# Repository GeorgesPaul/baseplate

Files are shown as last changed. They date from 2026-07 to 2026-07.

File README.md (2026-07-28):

# Baseplate

| | |
|---|---|
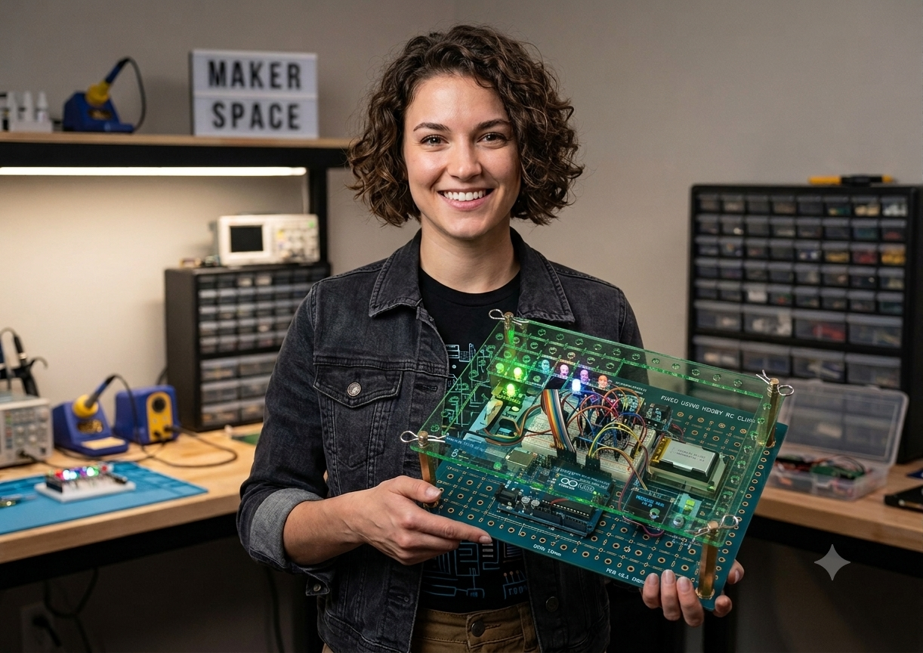
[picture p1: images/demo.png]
A finished stack with electronics mounted
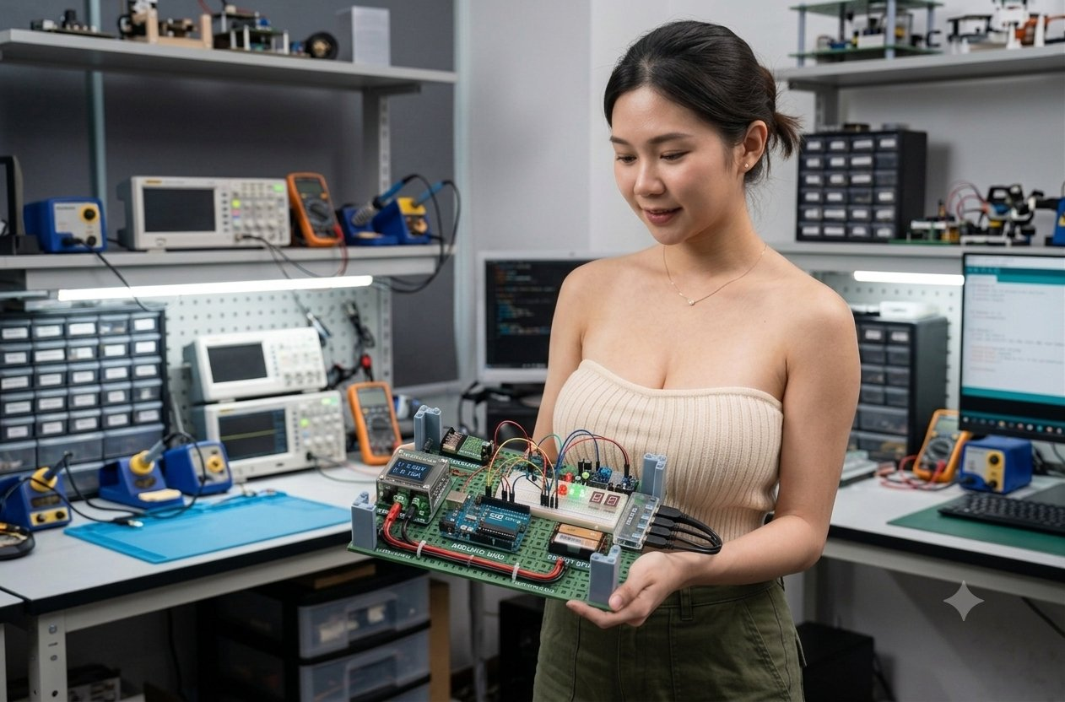
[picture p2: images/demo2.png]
A single plate carrying an Arduino, a breadboard and sensor modules
|  |  |

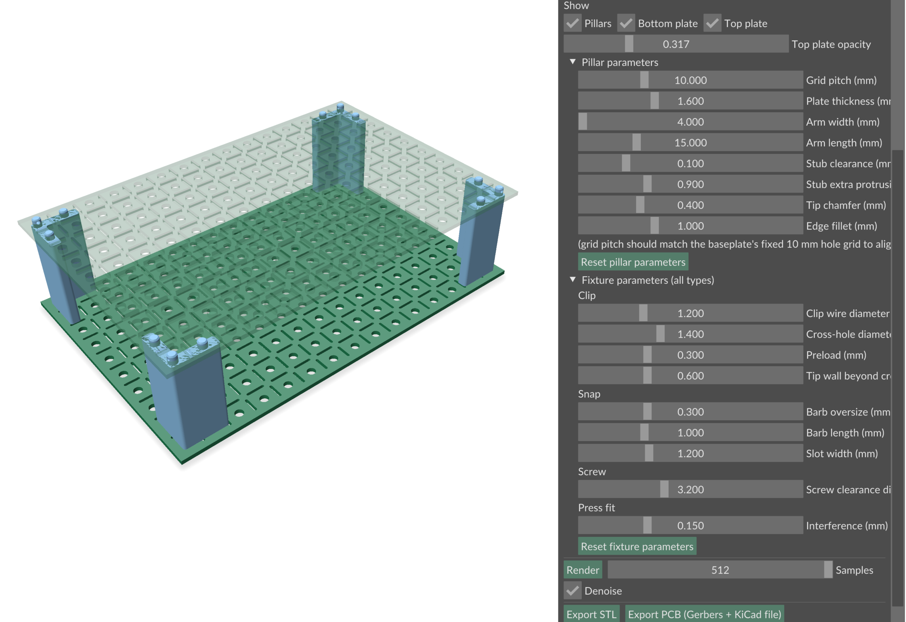
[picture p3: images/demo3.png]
The live parameter viewer: a 150x100 stack with the top plate at 32% opacity, next to the panel of sliders that drives it


A parametric prototyping stack: a snappable M3 grid plate fabricated as a PCB, plus 3D-printed
L-shaped corner pillars that hold two plates apart.

The plate is an ordinary 1.6 mm PCB with no copper: M3 clearance holes on a 10 mm grid, and milled
snap lines along every grid line so you can break any rectangular sub-plate out of a larger sheet by
hand. The pillars clip into those same holes, so a bottom plate, four pillars and a top plate make a
rigid enclosure-less chassis for a board, a battery, a sensor stack, or whatever else.

Everything is generated from code. The hole and slot pattern lives in one module
(`PCB/baseplate_geometry.py`) that feeds both the production KiCad board and the live 3D preview, so
the thing you look at is the thing that gets fabricated.

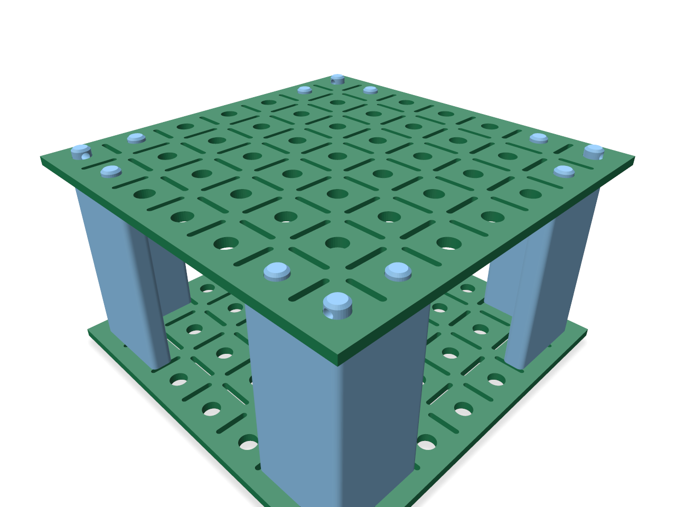
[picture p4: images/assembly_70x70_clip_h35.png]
70x70 assembly with clip pillars


## Configurations

Board size, pillar height and fixture type are all sliders in the viewer. A few points in that space:

### 40 x 40 mm, snap fixture, 20 mm pillars

The smallest useful stack. 16 M3 holes, 24 snap slots.

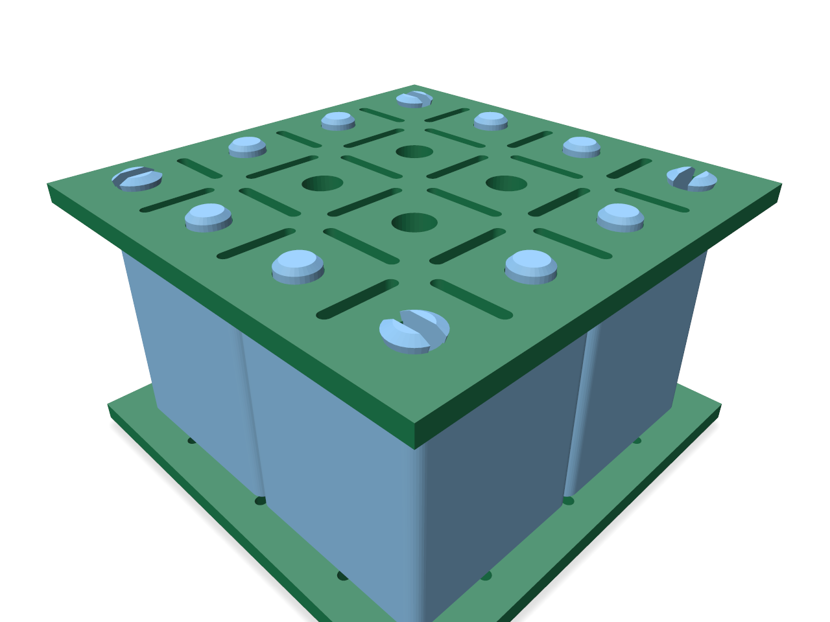
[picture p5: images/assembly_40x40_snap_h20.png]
40x40 snap assembly


### 70 x 70 mm, clip fixture, 35 mm pillars

The default. 49 M3 holes, 84 snap slots. Corner stubs are cross-drilled for an RC-style wire clip.

70x70 clip assembly

### 150 x 80 mm, screw fixture, 50 mm pillars

Boards do not have to be square. 120 M3 holes, 217 snap slots. Each pillar is bored through for a
single bolt that clamps both plates.

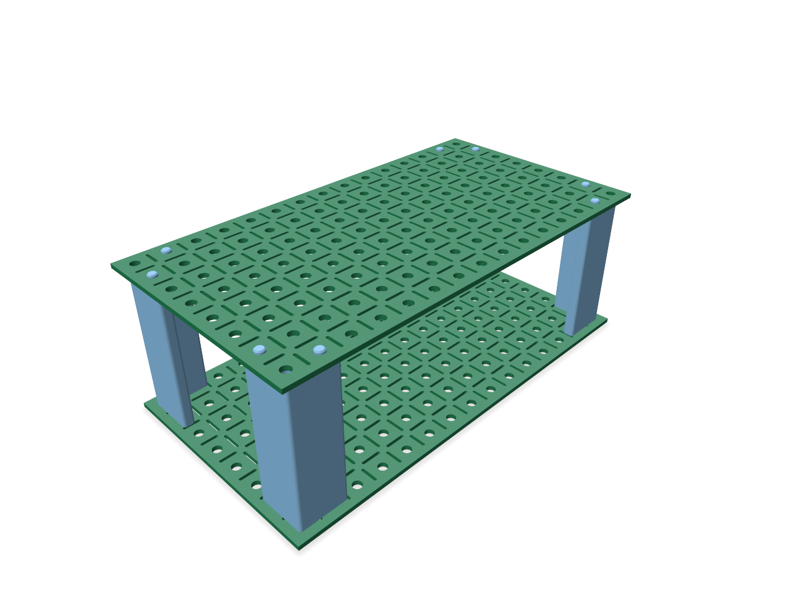
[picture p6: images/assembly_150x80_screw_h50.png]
150x80 screw assembly


### 250 x 250 mm, clip fixture, 50 mm pillars

The full panel, which is also the largest board most cheap fab houses take at the low price tier.
625 M3 holes, 1200 snap slots.

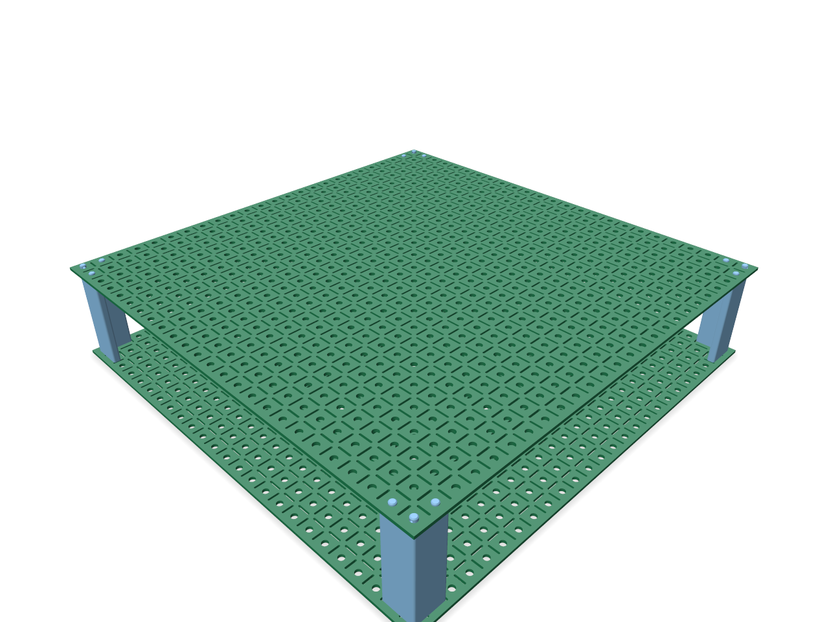
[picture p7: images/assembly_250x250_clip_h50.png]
250x250 clip assembly


### Top plate off

Pillars and each plate have their own show/hide checkbox, so you can drop the top plate and look at
what the corner stubs are actually doing. Here the clip fixture's cross-drilled holes are visible.

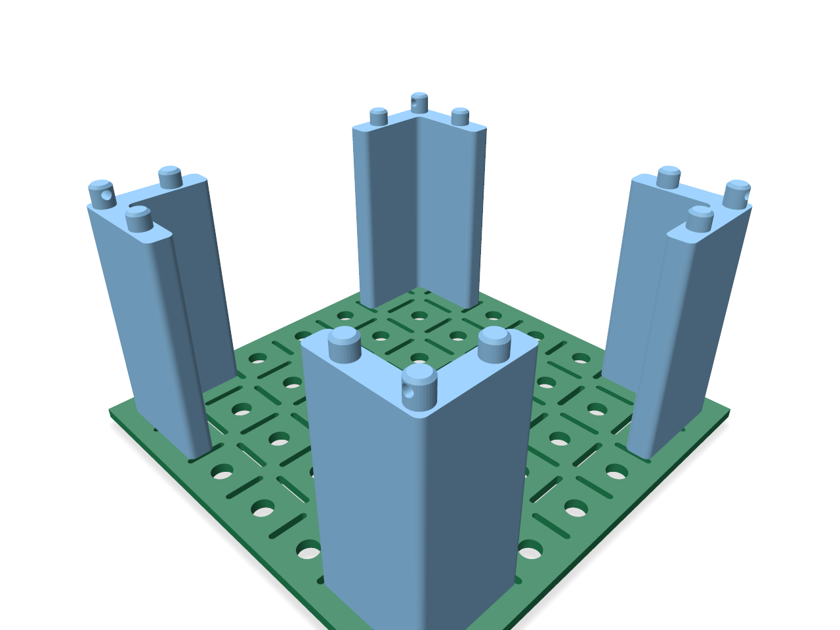
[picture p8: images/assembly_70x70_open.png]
70x70 assembly with the top plate hidden


### Top plate see-through

The top plate also has an opacity slider, for when you want the lid in place but still need to see
what is underneath it. Here it is at 40%.

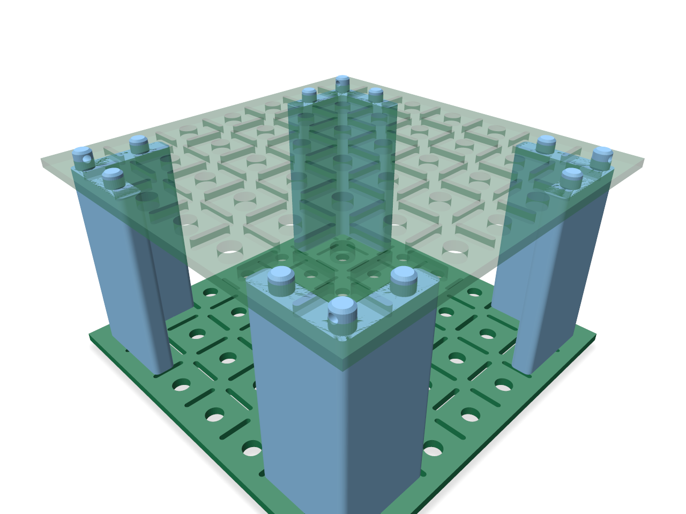
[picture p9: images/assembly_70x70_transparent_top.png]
70x70 assembly with a semi-transparent top plate


### Snap lines off

The break-off slots are a checkbox. Turn them off for a plain drilled grid plate: nothing to snap
along, nothing to crack in shipping, and the full stiffness of an uncut sheet.

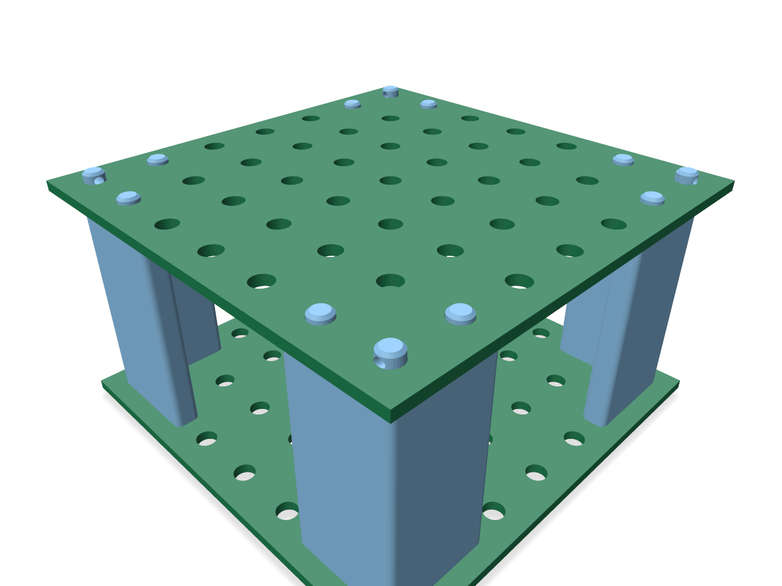
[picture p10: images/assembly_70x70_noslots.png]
70x70 assembly with no snap lines


## Fixture types

All four pillars share the same L-shaped body and the same three-stub footprint (corner stub plus one
stub a grid pitch away along each arm). Only the corner stub changes, which is what retains the plate.

| | |
|---|---|
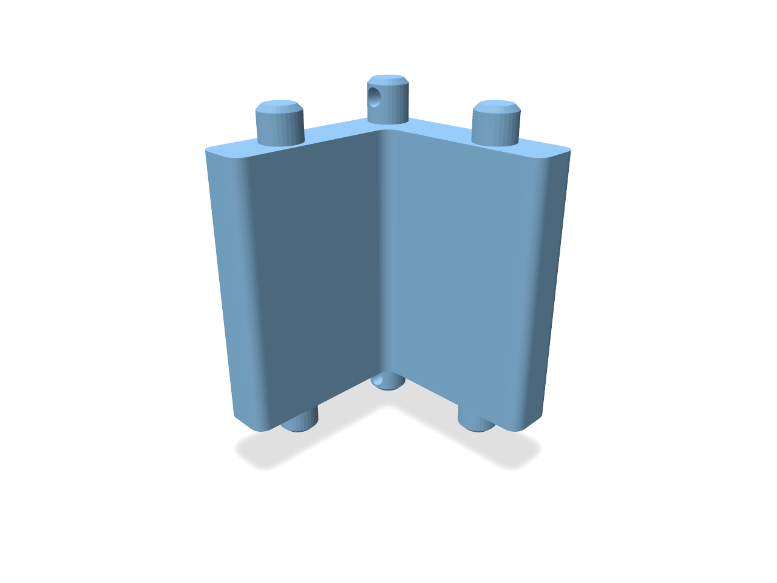
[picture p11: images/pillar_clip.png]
clip pillar
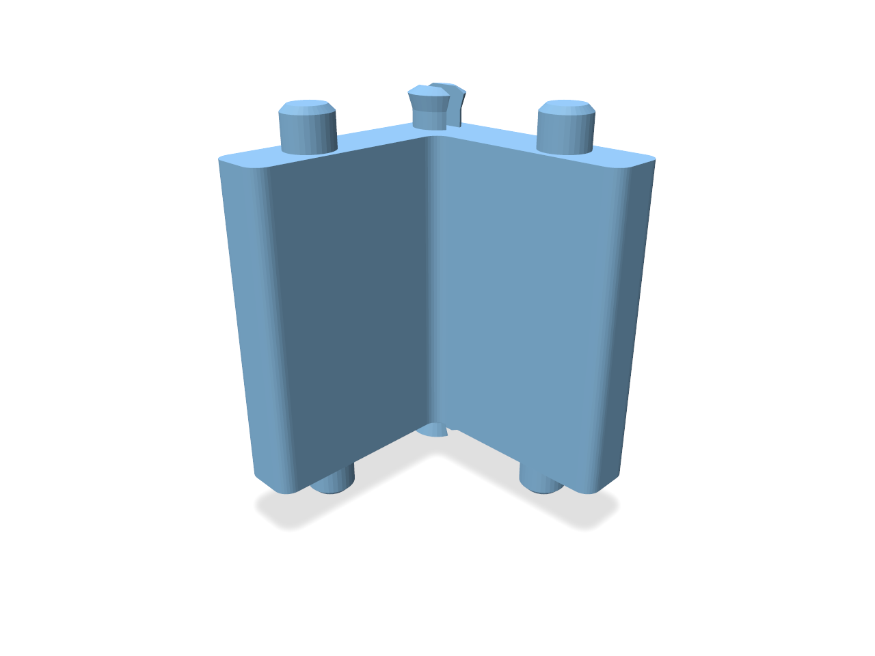
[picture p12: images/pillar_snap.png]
snap pillar
| **clip** <br> Cross-drilled stub for an RC-style wire clip. Preloaded so the installed clip clamps the plate down. <br>  | **snap** <br> Split cantilever boss with a barbed tip. No separate part to lose, and tolerant of stackup error. <br>  |
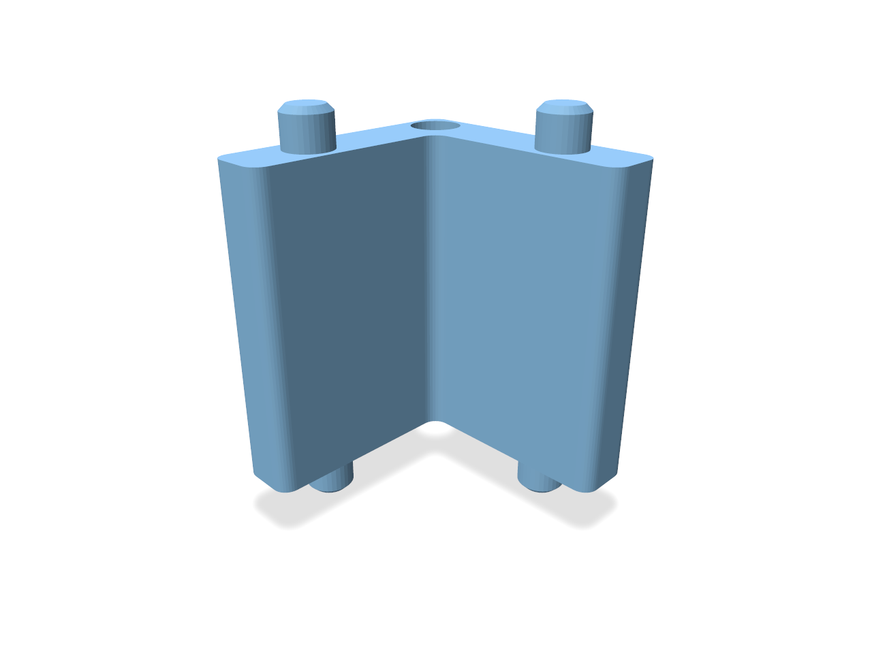
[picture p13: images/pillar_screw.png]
screw pillar
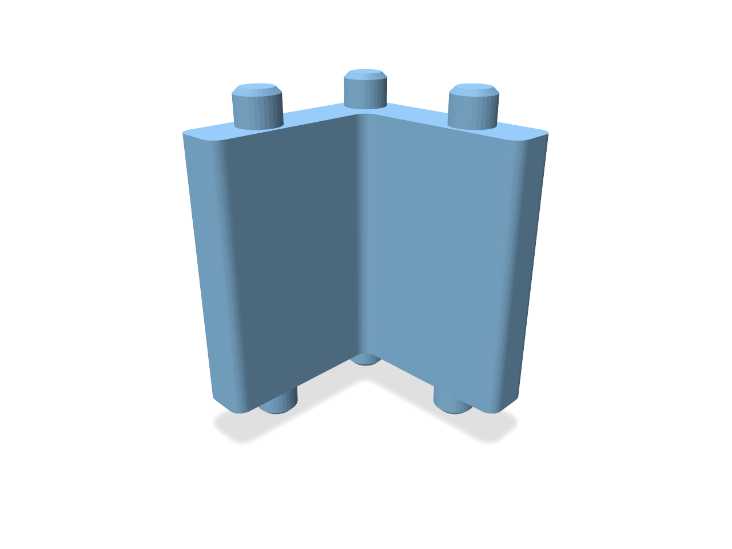
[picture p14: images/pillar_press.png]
press pillar
| **screw** <br> Plain slip-fit stubs plus a coaxial clearance bore through the whole body for one bolt. <br>  | **press** <br> Plain stubs sized for a light interference fit. Nothing else, for permanent stacks. <br>  |

Looking down at the corner stub, where the four types differ:

| clip | snap | screw | press |
|---|---|---|---|
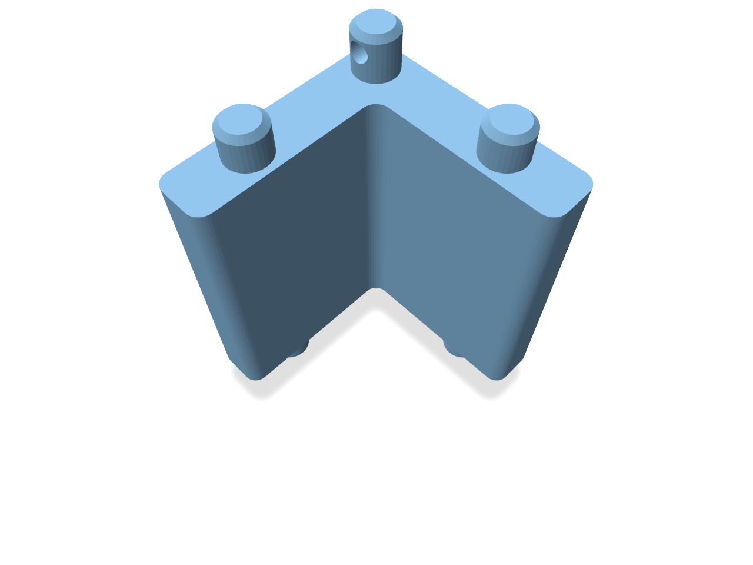
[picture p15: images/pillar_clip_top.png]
clip from above
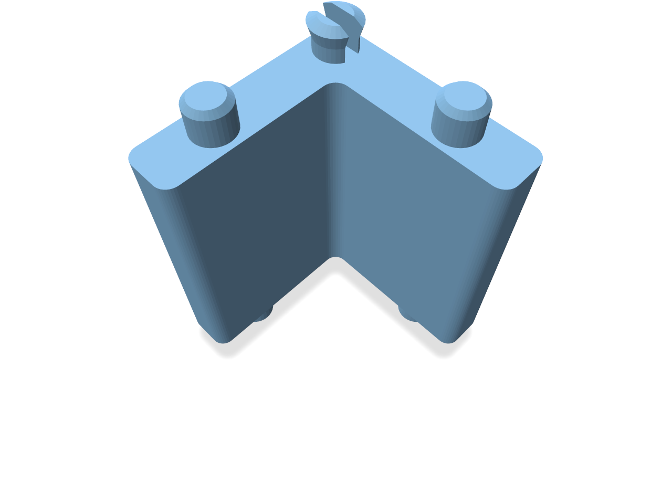
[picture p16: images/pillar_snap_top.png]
snap from above
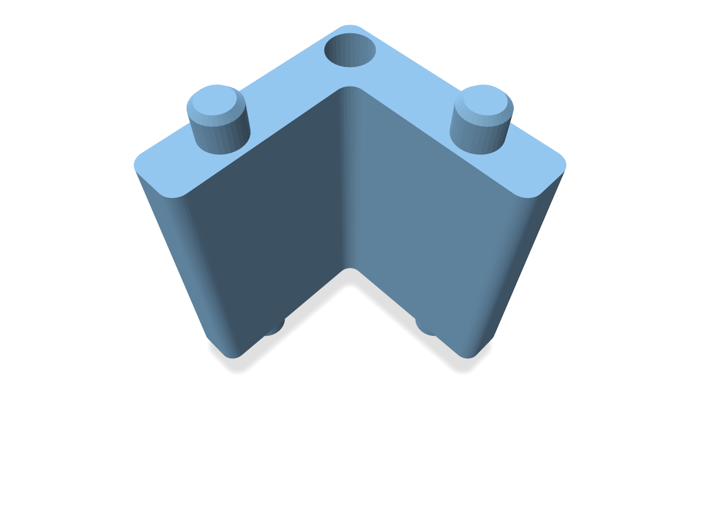
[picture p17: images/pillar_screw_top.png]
screw from above
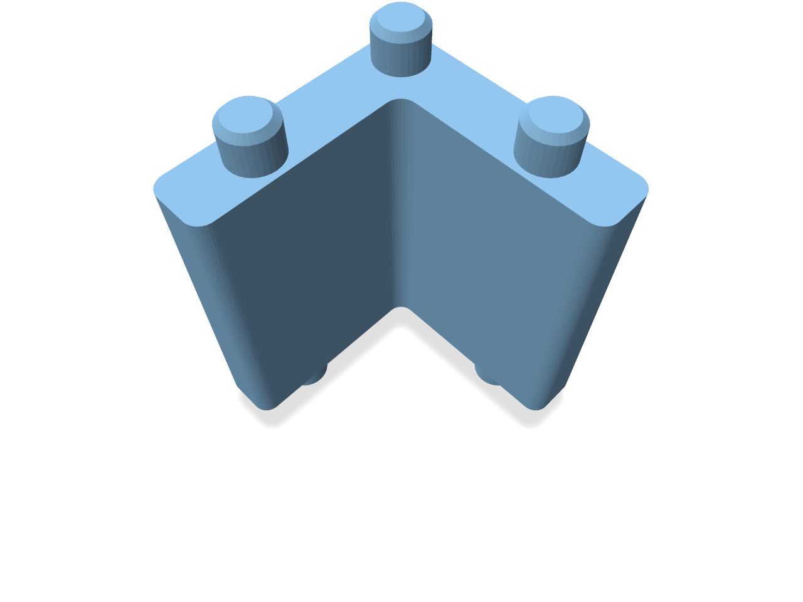
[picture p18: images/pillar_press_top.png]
press from above
|  |  |  |  |

## The board itself

Rendered from the generated KiCad file, 250 x 250 mm:

| Top | Perspective |
|---|---|
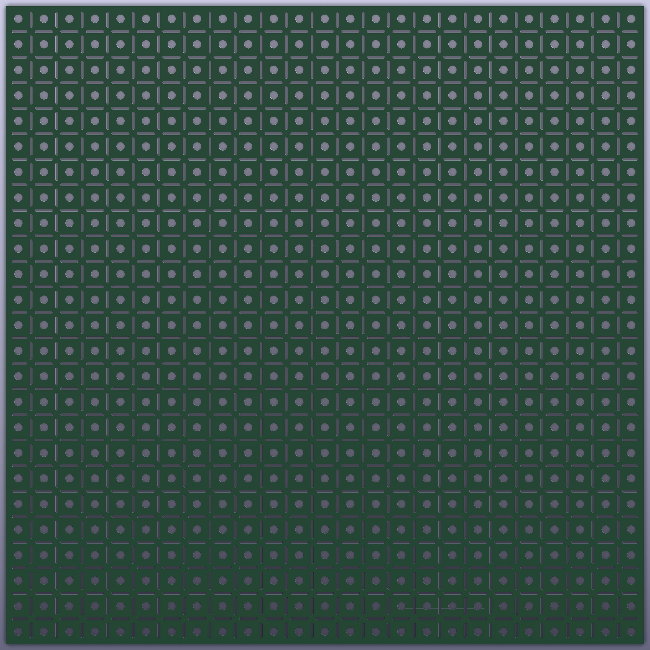
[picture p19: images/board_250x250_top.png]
board top render
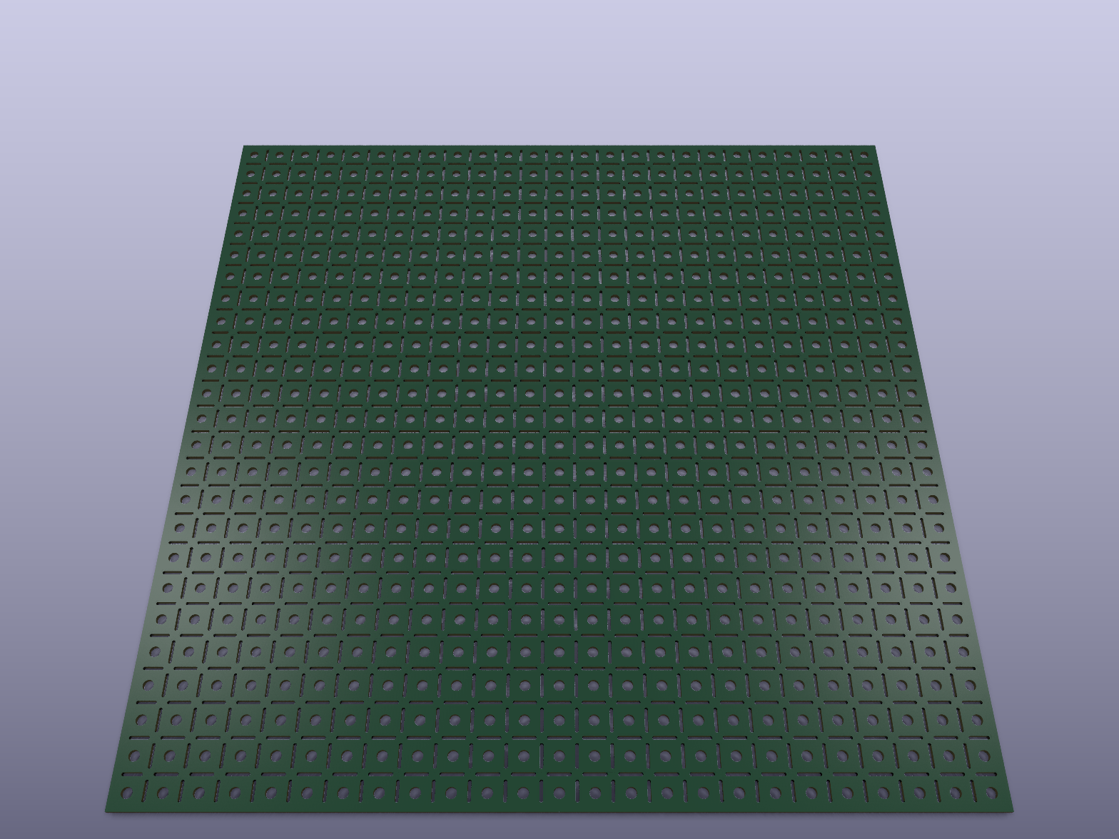
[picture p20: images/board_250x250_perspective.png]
board perspective render
|  |  |

Each 10 mm cell carries one M3 clearance hole in its center. Every interior grid line is a run of
1.0 mm milled NPTH slots, one per cell, each stopping short of the line crossings so a solid web
straddles every crossing. Those webs are the only thing holding the panel together along a break
line, and they are what you tune.

## Break-off strength

The 70 x 70 board close up, where the webs are legible:

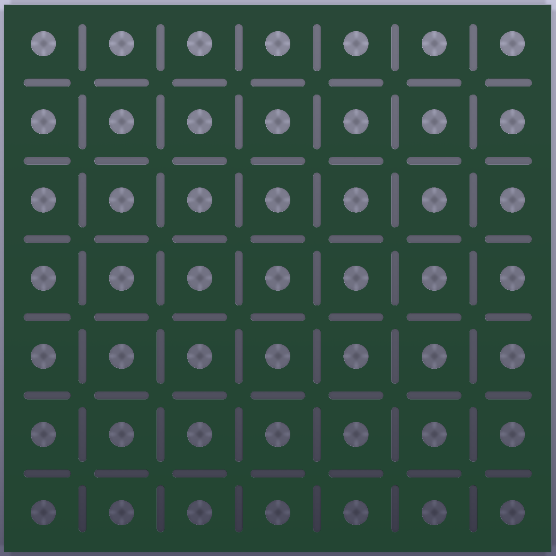
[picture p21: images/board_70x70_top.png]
70x70 board top render


Two numbers set how hard the panel is to snap:

- **`web`** (default 3.0 mm), the solid material left at each interior line crossing.
- **`edge_web`** (default 2.5 mm), the solid margin between the last slot and the board edge. This
  one matters more than its size suggests: the board edge is where a crack starts, so a thin edge web
  is what makes a panel come apart in the box.

Both are exposed as sliders in the viewer and as `--web` / `--edge-web` on the generator. The viewer
prints the resulting solid fraction of a break line as you drag them, and the generator prints it on
export:

```
snap slots: 84 (web 3 mm, edge web 2.5 mm)
  break line along X: 33% solid (23.0 mm of 70 mm)
  break line along Y: 33% solid (23.0 mm of 70 mm)
```

The first fabricated boards broke apart far too easily. That design used 2.5 mm webs and a 0.8 mm
edge web, and then perforated every web with a plus-pattern of 0.5 mm mouse bites. Three of those
bites landed directly on the break line, leaving about 1.0 mm of a 2.5 mm web as four 0.25 mm
ligaments, with the drilled holes acting as crack starters on top of that. A 70 mm break line held
roughly 7.6 mm of FR4.

The current design drops mouse bites entirely and widens both webs, so the same line holds 23 mm of
solid FR4 in continuous 3 mm ligaments with no stress risers. That is about three times the material
and a much larger jump in actual break force, since the notches are gone too. If it now errs the
other way for your handling, walk `web` back toward 2.0 mm; the sliders are there so you do not have
to guess twice.

## Running it

Dependencies are managed with [uv](https://docs.astral.sh/uv/).

```
uv run viewer.py
```

Optional, and only if you plan to use the **Render** button: installing LLVM lets mitsuba use its
vectorised CPU backend instead of the scalar one, which is worth about 25% off render time.

```
winget install LLVM.LLVM
```

Nothing to configure after that, and nothing breaks without it. See
[On GPUs and LLVM](#on-gpus-and-llvm) for why it is not bundled and why the gain is not larger.

That opens the live parameter viewer: drag sliders, watch the assembly rebuild. The board mesh is
cached on the parameters that affect it, so pillar-only tweaks stay interactive even at 250 x 250 mm.

The **Show** row has an independent checkbox for the pillars, the bottom plate and the top plate.
Anything unchecked is not built at all, not just hidden, so hiding the plates also makes rebuilds
faster while you tune pillar geometry. The top plate additionally has an opacity slider.

Two viewport settings adapt rather than being fixed, because both are expensive enough to matter on
a large display. Depth-peeled transparency is only switched on while the top plate is actually
translucent, and supersampling is dropped above ~2.5 Mpx, where the extra samples are invisible and
cost roughly double. Together those are worth about 4.5x the frame rate at 3840x2400.

mitsuba and the denoiser are only imported when you press **Render**, so they cost nothing on a
session that never uses them.

### The Render button

The live view is a rasterizer. It is fast and fine for working, but the board is mostly holes and
slots, and those only really read as depth once something traces shadow rays into them. The
**Render** button path-traces the current view with [mitsuba 3](https://www.mitsuba-renderer.org/)
and paints the result over the viewport; click or move the view and it disappears.

| Live view | Render button |
|---|---|
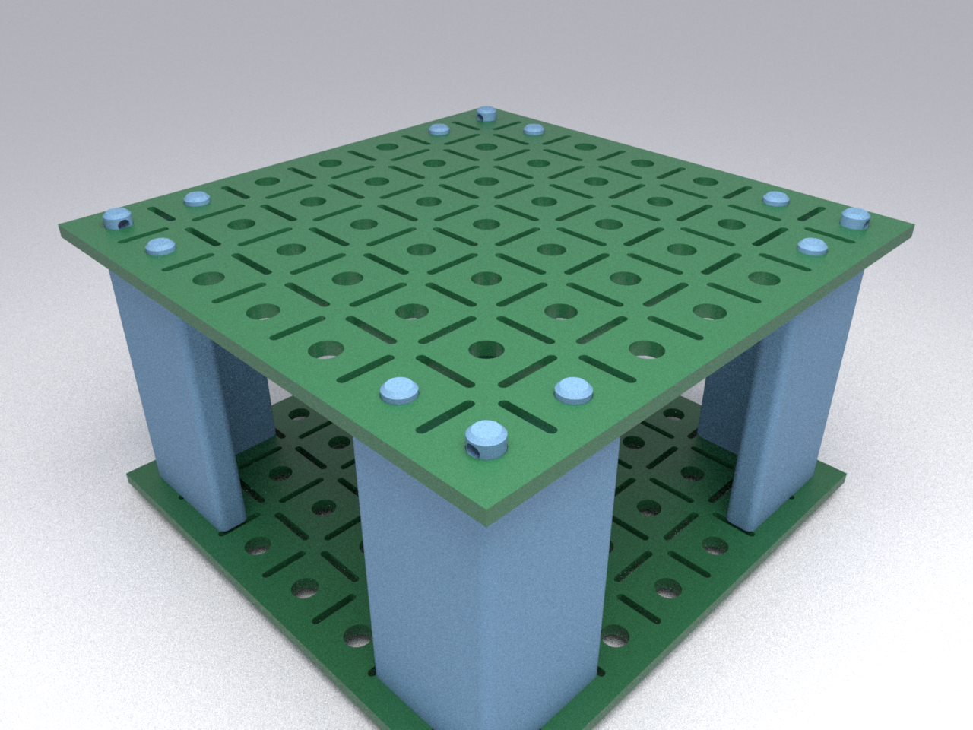
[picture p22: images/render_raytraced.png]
path-traced render
| rasterized viewport |  |

It respects everything the live view is showing, including top plate opacity:

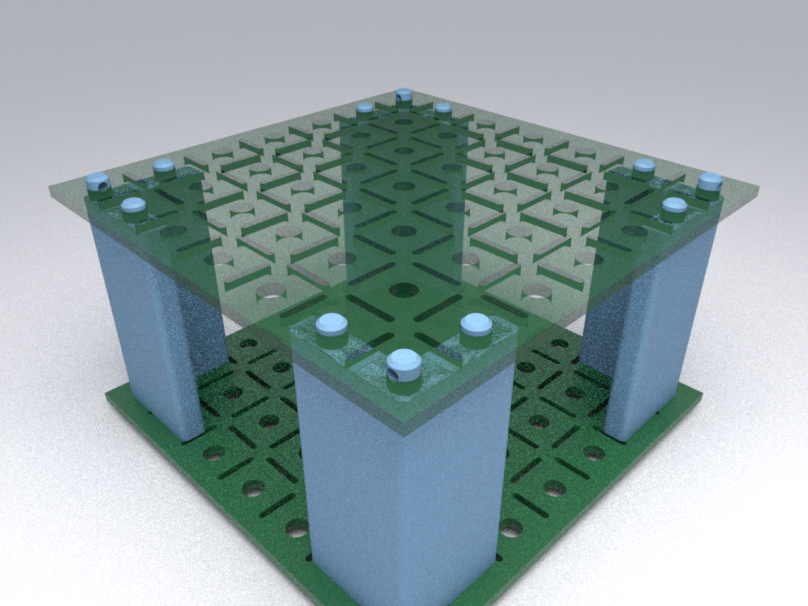
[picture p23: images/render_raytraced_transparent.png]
path-traced render with a semi-transparent top plate


Rendering runs on a worker thread. mitsuba releases the GIL while it traces, so the viewer keeps
drawing: the sample budget is split into eight passes and each one is painted as it lands, so you
watch the image resolve rather than watching a frozen window. A progress bar shows samples and
elapsed time, and **Cancel render** stops it between passes. Touching the view cancels it too.

The **Samples** slider trades time for noise, and **Denoise** runs
[Open Image Denoise](https://www.openimagedenoise.org/) over the result once the last pass lands.
The denoiser costs about half a second and is worth roughly an 8x sample budget, which is why the
default is only 64 samples. Turn Denoise off and you need ~512 samples for comparable cleanliness,
which takes minutes.

At 64 samples and 1280x960, the image above takes about **7 s** with LLVM installed and **9 s**
without, on a 16-core CPU.

### On GPUs and LLVM

Short version: on this machine, no. Longer version, since it is not obvious:

- **GPU.** mitsuba's GPU backend is CUDA/OptiX, so it needs an NVIDIA card. Dr.Jit has no AMD or
  Intel GPU backend at all, so an integrated Radeon or Arc cannot be used, and the OptiX denoiser is
  NVIDIA-only for the same reason. The CPU denoiser above is the substitute, and it is a bigger win
  than the GPU would have been for a render this small.
- **LLVM.** mitsuba's `llvm_ad_rgb` variant vectorises across SIMD lanes, and Dr.Jit loads LLVM at
  runtime instead of bundling it, finding it on Windows only via `DRJIT_LIBLLVM_PATH` or the DLL
  search path. Without it you silently get `scalar_rgb`, which is what the `jitc_llvm_init()`
  warning on startup is telling you. Note that this is not the same LLVM that numba uses: llvmlite
  links LLVM statically into its own DLL and does not expose the C API Dr.Jit needs, so having numba
  working is no help here.

  **Temper your expectations**: measured on this scene, LLVM is worth about 25% end to end (7.0 s
  against 9.2 s at 64 samples), not the multiple you might expect from "vectorised". Path tracing
  is branch-heavy and incoherent, which is close to the worst case for SIMD. Two things also had to
  be fixed before it was worth anything at all, both of which cost more than LLVM gained:

  - The JIT variants pay a fixed cost per kernel launch, so splitting the sample budget into eight
    passes for progress reporting cost a full second and made LLVM *slower* than scalar. Passes are
    now sized to a 16-sample floor, which puts the overhead back in the noise.
  - `max_depth` was 8. With no glass or metal in the scene, light has nothing left to do after a few
    diffuse bounces, and 5 renders 23% faster for a 0.02% difference in mean radiance.

To get the faster variant, install LLVM:

```
winget install LLVM.LLVM
```

(or the [official Windows installer](https://github.com/llvm/llvm-project/releases), which is the
same thing with a GUI). Either puts `LLVM-C.dll` in `C:\Program Files\LLVM\bin`. `render.py` looks
there on import and sets `DRJIT_LIBLLVM_PATH` itself, so there is nothing to configure afterwards:
restart the viewer and the `jitc_llvm_init()` warning is gone. On Linux, install your distribution's
LLVM runtime package; `render.py` checks `/usr/lib/libLLVM.so` the same way.

This is optional. Scalar already renders image tiles across every core, so it is a speedup, not a
fix for something broken.

Two buttons in the viewer export:

- **Export STL** writes the current pillar plus both plates to `things/`.
- **Export PCB** shells out to `PCB/generate_baseplate.py` for the current board size.

A one-frame smoke test that renders to a PNG and exits:

```
uv run viewer.py --screenshot out.png
```

Pillar STLs at the three stock heights (20 / 35 / 50 mm), without opening the viewer:

```
uv run pillars/pillar.py
```

## Generating the PCB

`generate_baseplate.py` needs `pcbnew` and `kicad-cli`, which only exist inside KiCad's own bundled
Python, not the uv venv. Run it with that interpreter:

```
cd PCB
"%LOCALAPPDATA%/Programs/KiCad/10.0/bin/python.exe" generate_baseplate.py 250 250
```

(The viewer's **Export PCB** button finds that interpreter itself, searching `%LOCALAPPDATA%\Programs\KiCad`
and `C:\Program Files\KiCad`.)

Arguments:

| | |
|---|---|
| `WIDTH [HEIGHT]` | board size in mm, rounded to the 10 mm grid; square if only width is given |
| `--hole-d MM` | grid hole diameter (default 3.2) |
| `--no-snap-lines` | omit the break-off slots entirely |
| `--web MM` | solid web at each line crossing (default 3.0) |
| `--edge-web MM` | solid margin between the last slot and the board edge (default 2.5) |

It writes `baseplate_<W>x<H>.kicad_pcb`, Gerbers and Excellon drills into `production_<W>x<H>/`, and
a ready-to-upload `baseplate_<W>x<H>_gerbers.zip`.

The board is first written in a conservative s-expression format, then reloaded and resaved through
`pcbnew` so the file ends up in the native format of the installed KiCad version.

## Layout

```
viewer.py                     live parameter viewer (polyscope + imgui)
render.py                     path-traced render for the Render button (mitsuba 3 + OIDN)
pillars/pillar.py             parametric L-pillar generator (manifold3d), STL export
PCB/baseplate_geometry.py     hole/slot pattern, single source of truth
PCB/baseplate_mesh.py         manifold3d board model for the viewer
PCB/generate_baseplate.py     KiCad board + Gerber/drill export
PCB/production_<W>x<H>/       generated fab output (not committed)
things/                       exported STLs (not committed)
images/                       screenshots used by this README
```

Fab output, meshes and 3D renders are build products and stay out of the repo; run the commands above
to regenerate any of them.

## Key dimensions

| | |
|---|---|
| Grid pitch | 10 mm |
| M3 clearance hole | 3.2 mm NPTH |
| Plate thickness | 1.6 mm |
| Snap slot width | 1.0 mm |
| Web at line crossings | 3.0 mm (tunable) |
| Edge web | 2.5 mm (tunable) |
| Stock pillar heights | 20 / 35 / 50 mm |
| Pillar arm width / length | 4 mm / 15 mm |

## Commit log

2026-07-28 Initial commit: parametric M3 baseplate + pillar generator
    Snappable 10 mm M3 grid plate fabricated as a bare PCB, plus parametric
    L-shaped corner pillars in four fixture variants (clip, snap, screw,
    press). The hole/slot pattern is shared between the KiCad board generator
    and the manifold3d preview so the viewer always matches what gets made.
    Adds a README with rendered screenshots of several configurations.
    Generated fab output (Gerbers, drills), STLs and 3D renders are gitignored;
    images/ holds only the renders the README points at.
    [baseplate_250x250.kicad_pcb, baseplate_70x70.kicad_pcb]
2026-07-28 Strengthen break-off geometry, drop mouse bites, make snap lines optional
    The first fabricated boards came apart far too easily. The old design left
    2.5 mm webs at each line crossing and a 0.8 mm edge web, then perforated
    every web with a plus-pattern of 0.5 mm mouse bites. Three of those bites
    sat directly on the break line, so a 2.5 mm web was really about 1.0 mm of
    material in four 0.25 mm ligaments, with drilled holes as crack starters.
    A 70 mm break line held roughly 7.6 mm of FR4.
    - Remove mouse bites entirely. The webs are now continuous, which kills the
    stress risers as well as recovering the material.
    - Raise the defaults to 3.0 mm webs and a 2.5 mm edge web. The edge web is
    th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
    [baseplate_250x250.kicad_pcb, baseplate_70x70.kicad_pcb]
2026-07-28 Split plate visibility into two checkboxes, tidy up the render
    - Replace the single "Show plates" checkbox with independent Pillars /
    Bottom plate / Top plate checkboxes, so the lid can be taken off to see
    what the corner stubs are doing. Unchecked meshes are skipped in
    rebuild() rather than hidden, so this also speeds up pillar tuning.
    - Plates are now solder-mask green and pillars light blue. Polyscope
    materials are matcaps that wash colors out, so the constants are
    pre-compensated and deliberately darker than the colors they render as.
    - Use the "clay" material (matte, no blown-out specular on the big flat
    plate faces), a white background, softened ground shadows, and
    supers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
2026-07-28 Add top plate opacity and a path-traced Render button
    The live view is a rasterizer, and the board is mostly holes and slots, which
    only read as depth once something traces shadow rays into them. Render hands
    the current meshes and the current camera to mitsuba 3 and paints the result
    back over the viewport as a fullscreen image quantity.
    - Top plate opacity slider, applied through polyscope's "pretty" transparency
    mode. It pokes the registered mesh directly rather than triggering a
    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
2026-07-28 Render progressively on a worker thread, and denoise
    The render used to block the viewer with no feedback beyond a frozen window.
    mitsuba releases the GIL while it traces, so it can run on a worker thread
    and the viewer keeps drawing.
    - Split the sample budget into eight passes and publish each one as it
    lands, so the image visibly resolves instead of appearing at the end. A
    progress bar shows samples and elapsed time.
    - Cancel render stops between passes; touching the view cancels too, as does
    any rebuild. Cancelling bumps shown_version, because the worker can publish
    one more pass before it sees the flag and that straggler would otherwise
    put the overlay straight back up.
    - Pass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
2026-07-28 Stop the progress passes from cancelling out the LLVM speedup
    Installing LLVM made rendering no faster, and with the default settings
    slightly slower. Two causes, measured on the 70x70 assembly at 64 spp,
    1280x960:
    - The JIT variants pay a fixed cost per kernel launch, which the scalar
    variant does not. Splitting the budget into eight passes for progress
    reporting cost llvm_ad_rgb a full second (8.37 s in one pass, 9.36 s in
    eight) while costing scalar_rgb nothing, which was enough to put LLVM
    behind. 1, 2 and 4 passes all land within 0.15 s of each other, so passes
    are now sized to a 16-sample floor with a cap of 8: 64 spp becomes 4x16
    instead of 8x8, and large budgets still ge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
2026-07-28 Stop paying for depth peeling and supersampling that nothing needs
    The interactive viewer had got much heavier, and not because of anything to
    do with the renderer: neither mitsuba nor drjit is even imported until the
    Render button is pressed. It was two viewport settings added earlier in the
    same session, and they multiply.
    Measured with screenshot_to_buffer, which forces a full draw (frame_tick
    stops drawing once the window is unfocused, so it measures nothing here).
    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
2026-07-28 README: add the viewer screenshot below the demo photos
    demo3.png shows the live parameter panel driving a 150x100 stack with the
    top plate part-transparent. Full width rather than in the two-column table,
    because the slider labels need the pixels to stay legible.
